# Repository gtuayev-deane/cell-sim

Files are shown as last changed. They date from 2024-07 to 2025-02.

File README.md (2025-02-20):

# Cell Simulator

This cell-sim is designed to mimic a LiPo battery pack for develpoment of the surrounding electronics, like a BMS.

- 16 channels
- Open-Source hardware design, you can embed onto your own HIL setup
- ⚡️ 0-4.5V and 0-500mA per channel
- DMM muxed to each channel for arbitarily precise measurment
- Open-circuit simulation on each channel
- 📏 16bit ADC feedback for voltage and current
- 🔌 USB w/ Python software interface (+ 100MBit Ethernet + WiFi waiting for firmware support)



## Design overview

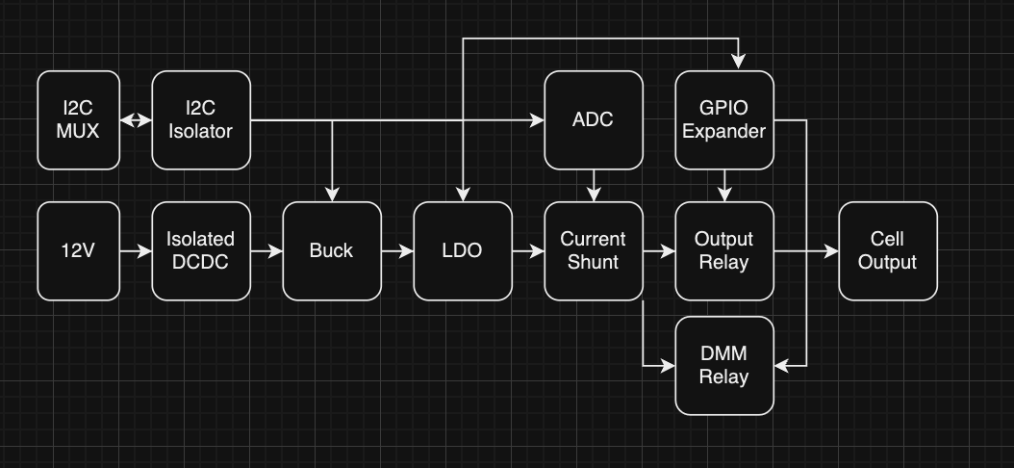
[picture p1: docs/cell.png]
Cell Diagram


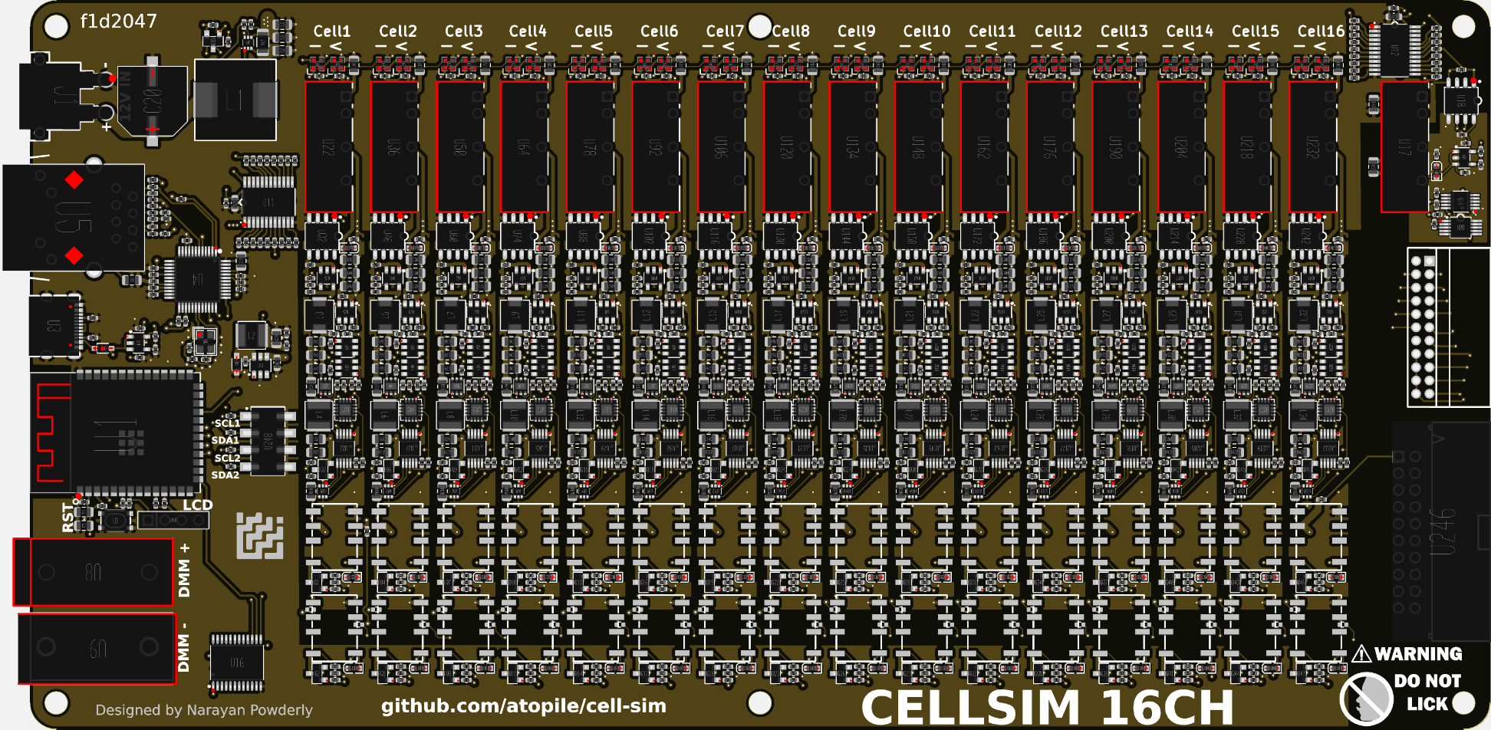
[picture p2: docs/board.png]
Board Render


## Getting Started

1. Install python if you don't have it already
2. Install the requirements `pip install -r requirements.txt`
3. Connect the board via USB
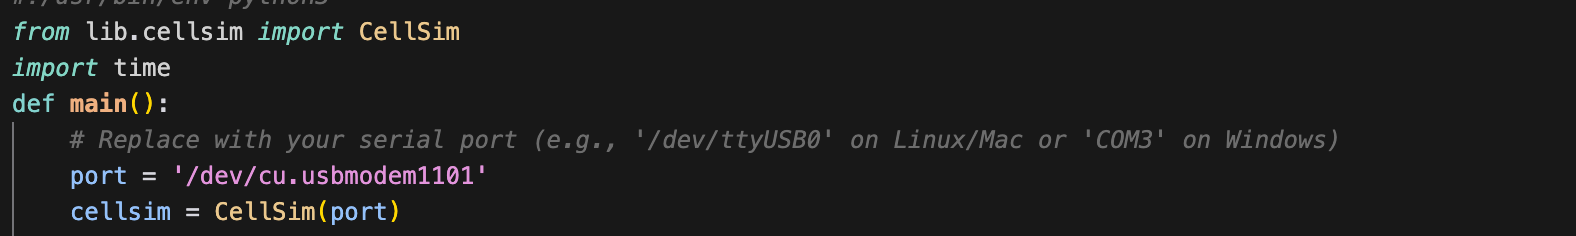
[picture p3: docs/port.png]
Port

4. Power the board with the 12V input (supply: 1A minimum, 3A recommended)
5. Run the example python script `python example_set_voltages.py`
6. Voltages should be set to 3.5V, then rainbow from 1V to 4V across the 16 channels and current should be close to 0A.

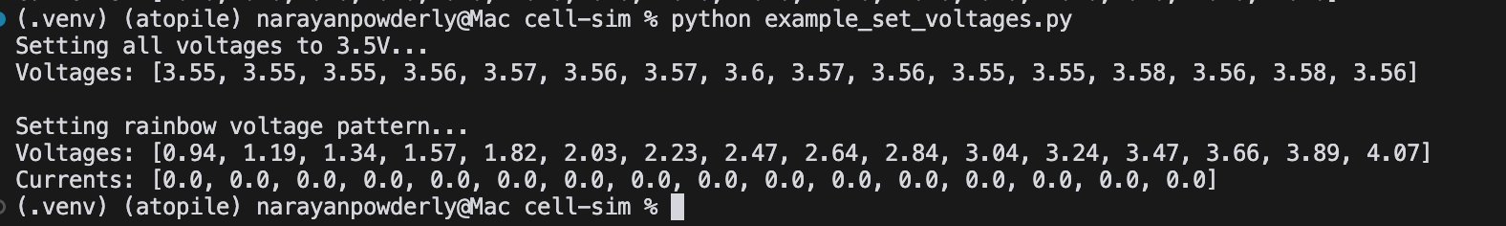
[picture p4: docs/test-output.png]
Test Output


You should see something like this:
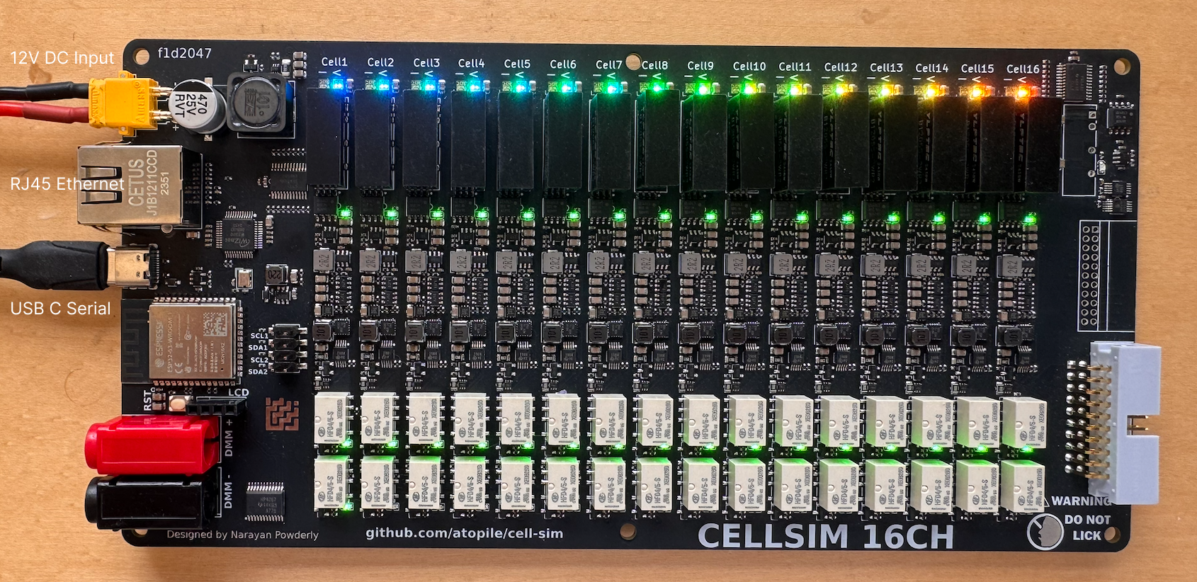
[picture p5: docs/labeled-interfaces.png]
Rainbow


## Notes
1. To get best low noise performance, use a quality power supply for the input supply.

## Firmware

### Update Firmware
We use PlatformIO to build and upload the firmware via USB.
1. Install PlatformIO: https://platformio.org/install
2. Connect the board via USB (might need to accept connection popup on Mac)
3. Run `pio run -t upload` or install the PlatformIO VSCode extension and use the upload button.

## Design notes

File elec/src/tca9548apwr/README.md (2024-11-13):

# TCA9548APWR I2C Multiplexer

The TCA9548APWR is an I2C multiplexer that allows you to connect up to 8 I2C devices with the same address to a single I2C bus. Its kind of weird to need this, but it's a thing.

tca9548apwr



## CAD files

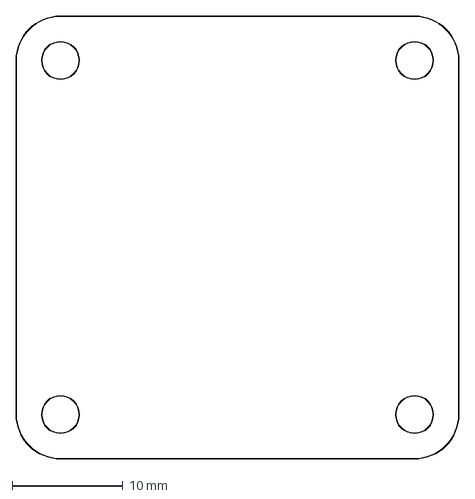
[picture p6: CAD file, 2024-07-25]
elec/src/tca9548apwr/mech/template_40x40.dxf
40.0 x 40.0 mm

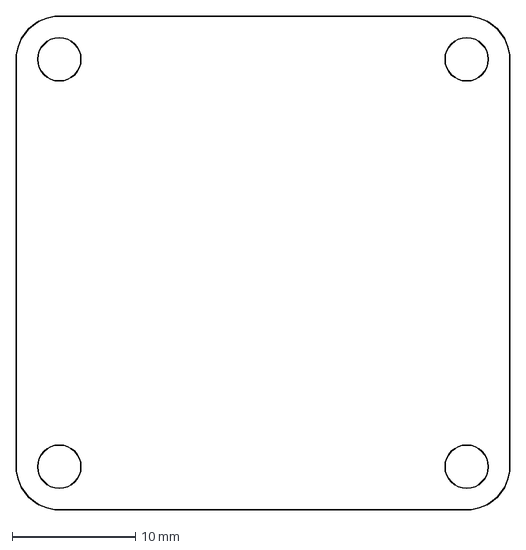
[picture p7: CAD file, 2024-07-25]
elec/src/tca9548apwr/mech/template_outline.dxf
40.0 x 40.0 mm

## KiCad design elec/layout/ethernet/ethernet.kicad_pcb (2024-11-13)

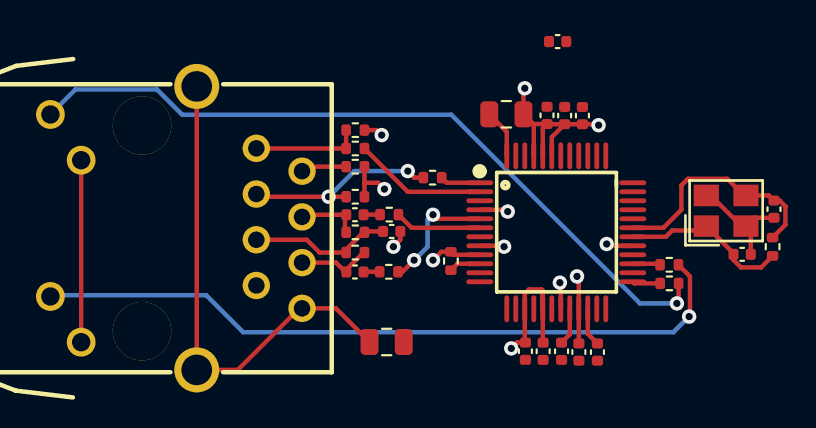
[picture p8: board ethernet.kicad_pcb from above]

Board: 2 copper layers, 32 parts (0 on the bottom side), 27 nets.

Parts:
C1: 50V 1nF X7R ±10% 0805 Multilayer Ceramic Capacito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; C0805
C2: 50V 22nF X7R ±10% 0402 Multilayer Ceramic Capacit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; C0402
C3, C4: 50V 6.8nF X7R ±10% 0402 Multilayer Ceramic Capaci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; C0402
C5, C6: 50V 10nF X7R ±10% 0402 Multilayer Ceramic Capacit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; C0402
C7: 10V 4.7uF X5R ±20% 0402 Multilayer Ceramic Capaci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; C0402
C8, C9, C10, C11, C12, C13: 16V 100nF X7R ±10% 0402 Multilayer Ceramic Capaci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; C0402
C14: 25V 10uF X5R ±10% 0805 Multilayer Ceramic Capacit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; C0805
C15, C16: 50V 10pF C0G ±5% 0402 Multilayer Ceramic Capacito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; C0402
R1, R2: 62.5mW Thick Film Resistors 50V ±100ppm/℃ ±1% 200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; R0402
R3, R4, R8, R9: 62.5mW Thick Film Resistors 50V ±100ppm/℃ ±1% 33Ω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; R0402
R5, R6, R10, R11: 62.5mW Thick Film Resistors 50V ±100ppm/℃ ±1% 49.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; R0402
R7: 62.5mW Thick Film Resistors 50V ±1% ±200ppm/℃ 10Ω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; R0402
R12: 62.5mW Thick Film Resistors 50V ±100ppm/℃ ±1% 12.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; R0402
R13: 62.5mW Thick Film Resistors 50V ±100ppm/℃ ±1% 1MΩ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; R0402
U1: ?; LQFP-48_L7.0-W7.0-P0.50-LS9.0-BL
U2: ?; RJ45-TH_J1B1211CCD
U3: ?; CRYSTAL-SMD_4P-L3.2-W2.5-BL

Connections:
_1v2o: C6.1, U1.22
actled: R2.1, U1.27
cgnd: C1.1, U2.8, U2.13, U2.14
exres1: R12.1, U1.10
gnd-1: C1.2, C2.2, C5.2, C6.2, C7.2, C8.2, C9.2, C10.2, C11.2, C12.2, C13.2, C14.2, R12.2, U1.3, U1.9, U1.14, U1.16, U1.19, U1.29, U1.48
linkled: R1.1, U1.25
lled_minus: R1.2, U2.9
nc: U1.12, U1.13, U1.46, U1.47
oscillator-gnd: C15.2, C16.2, U3.2, U3.4
rct: C5.1, R10.2, R11.2, U2.5
rd_minus: C3.2, R10.1, U2.6
rd_plus: C4.2, R11.1, U2.4
rled_minus: R2.2, U2.11
rsvd: U1.23, U1.38, U1.39, U1.40, U1.41, U1.42
rx_minus_damping-vcc: C3.1, R8.2
rx_plus_damping-vcc: C4.1, R9.2
rxn: R8.1, U1.5
rxp: R9.1, U1.6
tct: C2.1, R7.2, U2.2
td_minus: R4.2, R6.2, U2.3
td_plus: R3.2, R5.2, U2.1
tocap: C7.1, U1.20
txn: R4.1, U1.1
txp: R3.1, U1.2
vcc: C8.1, C9.1, C10.1, C11.1, C12.1, C13.1, C14.1, R5.1, R6.1, R7.1, U1.4, U1.8, U1.11, U1.15, U1.17, U1.21, U1.28, U1.43, U1.44, U1.45, U2.10, U2.12
xi_slash_clkin: C15.1, R13.1, U1.30, U3.1
xo: C16.1, R13.2, U1.31, U3.3

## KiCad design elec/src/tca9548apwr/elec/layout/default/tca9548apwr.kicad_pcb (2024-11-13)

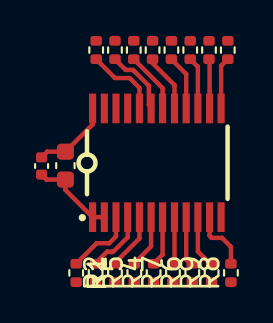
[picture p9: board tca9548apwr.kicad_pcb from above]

Board: 2 copper layers, 20 parts (0 on the bottom side), 19 nets.

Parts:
C1: 16V 100nF X7R ±10% 0402 Multilayer Ceramic Capaci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; C0402
C2: 16V 2.2uF X5R ±10% 0603 Multilayer Ceramic Capaci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; C0603
R1, R2, R3, R4, R5, R6, R7, R8, R9, R10, R11, R12, R13, R14, R15, R16, R17: 62.5mW Thick Film Resistors 50V ±100ppm/℃ ±1% 10k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; R0402
U1: TSSOP-24_L7.8-W4.4-P0.65-LS6.4-BL

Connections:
ic-gnd: C1.2, C2.2, U1.1, U1.2, U1.12, U1.21
ic-scl: R2.2, U1.5
ic-scl-1: R4.2, U1.7
ic-scl-2: R6.2, U1.9
ic-scl-3: R8.2, U1.11
ic-scl-4: R10.2, U1.14
ic-scl-5: R12.2, U1.16
ic-scl-6: R14.2, U1.18
ic-scl-7: R16.2, U1.20
ic-sda: R3.2, U1.4
ic-sda-1: R5.2, U1.6
ic-sda-2: R7.2, U1.8
ic-sda-3: R9.2, U1.10
ic-sda-4: R11.2, U1.13
ic-sda-5: R13.2, U1.15
ic-sda-6: R15.2, U1.17
ic-sda-7: R17.2, U1.19
reset_: R1.1, U1.3
vcc: C1.1, C2.1, R1.2, R2.1, R3.1, R4.1, R5.1, R6.1, R7.1, R8.1, R9.1, R10.1, R11.1, R12.1, R13.1, R14.1, R15.1, R16.1, R17.1, U1.24

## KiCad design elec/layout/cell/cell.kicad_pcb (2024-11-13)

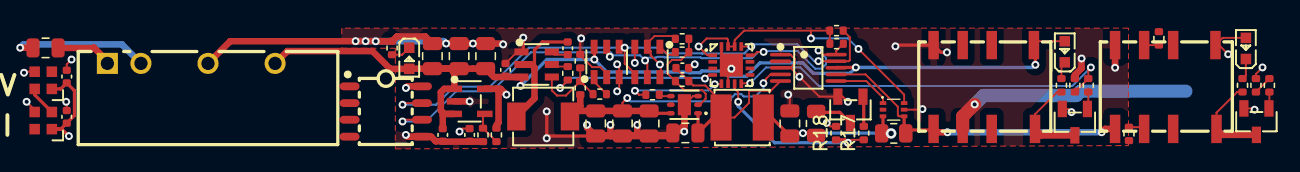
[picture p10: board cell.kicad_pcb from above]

Board: 4 copper layers, 63 parts (0 on the bottom side), 40 nets.

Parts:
C1: 50V 2.2uF X5R ±10% 0805 Multilayer Ceramic Capaci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; C0805
C2, C3, C4, C6, C7, C8, C11, C12: 25V 10uF X5R ±10% 0805 Multilayer Ceramic Capacit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; C0805
C5, C9, C13, C14: 16V 100nF X7R ±10% 0402 Multilayer Ceramic Capaci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; C0402
C10, C15, C16: 25V 1uF X5R ±10% 0402 Multilayer Ceramic Capacito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; C0402
L1: ?; IND-SMD_L4.4-W4.2
L2: ?; IND-SMD_L4.0-W4.0
LED1, LED2, LED3: ?; LED0603-RD
Q1, Q2, Q3: ?; SOT-23-3_L2.9-W1.3-P1.90-LS2.4-BR
R1: 62.5mW Thick Film Resistors 50V ±100ppm/℃ ±1% 14k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; R0402
R2: 62.5mW Thick Film Resistors 50V ±100ppm/℃ ±1% 24k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; R0402
R3: 62.5mW Thick Film Resistors 50V ±100ppm/℃ ±1% 37.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; R0402
R4, R5, R8, R9, R12, R15, R18, R20, R21, R24, R25: 62.5mW Thick Film Resistors 50V ±100ppm/℃ ±1% 10k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; R0402
R6: 62.5mW Thick Film Resistors 50V ±100ppm/℃ ±1% 43k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; R0402
R7: 62.5mW Thick Film Resistors 50V ±100ppm/℃ ±1% 60.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; R0402
R10: 125mW Thick Film Resistors 150V ±1% 100mΩ 0805 Ch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; R0805
R11, R14: 62.5mW Thick Film Resistors 50V ±100ppm/℃ ±1% 13k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; R0402
R13, R16, R17: 62.5mW Thick Film Resistors 50V ±100ppm/℃ ±1% 1kΩ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; R0402
R19: 125mW Thick Film Resistors 150V ±100ppm/℃ ±1% 226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; R0805
R22: 62.5mW Thick Film Resistors 50V ±100ppm/℃ ±1% 11.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; R0402
R23: 62.5mW Thick Film Resistors 50V ±100ppm/℃ ±1% 6.2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; R0402
U1: ?; PWRM-TH_BXXXXS-2WR2
U2: ?; MSOP-10_L3.0-W3.0-P0.50-LS5.0-BL
U3, U4, U5: ?; SOT-23-6_L2.9-W1.6-P0.95-LS2.8-BL
U6: ?; WSON-6_L2.0-W2.0-P0.65-TL-EP
U7: ?; SOT-563_L1.6-W1.2-P0.50-LS1.6-TL
U8, U9: ?; RELAY-SMD_HFD4-5-SR
U10: ?; QFN-16_L3.0-W3.0-P0.50-BL-EP1.7
U11: ?; SOIC-8_L4.9-W3.9-P1.27-LS6.0-TL
U12, U13: ?; LED-SMD_4P-L2.0-W2.0-BR
U14: ?; SOT-23-5_L3.0-W1.7-P0.95-LS2.8-BL

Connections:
adc-vcc: C6.1, C7.1, C8.1, L1.2, R3.1, U2.4, U6.6
adc-vcc-1: C10.1, C11.1, L2.1, R7.1, U2.5, U6.1
adc-vcc-2: R10.2, U2.7, U7.4, U8.5, U9.5
ain2: U2.6, U7.1
buck-enable: R5.1, U10.4
buck.dac-vout: R2.1, U3.1
buck.regulator-en: R5.2, U4.5
dmm_relay-gnd: R25.1, U9.3
dmm_relay-vcc: R24.1, U9.6
dmm_relay.fet-gate: Q2.1, R15.2
dmm_relay.indicator_led.resistor-cathode: LED3.1, R14.1
dmm_relay.relay-gnd: Q2.3, R14.2, U9.8
dmm_relay_enable: R15.1, R16.1
fb: R6.2, R7.2, R8.1, U6.2
gnd: C1.2, U1.2
gnd-2: C13.2, C14.2, Q2.2, R16.2, U12.3, U13.3
gnd-6: C2.2, C3.2, C4.2, C5.2, C6.2, C7.2, C8.2, C10.2, C11.2, C12.2, C15.2, C16.2, Q1.2, Q3.2, R1.2, R4.2, R8.2, R13.2, R18.2, R23.2, U1.4, U2.1, U2.3, U3.2, U4.1, U5.2, U5.6, U6.3, U6.7, U7.2, U7.5, U8.4, U9.4, U10.6, U10.16, U10.17, U11.5, U14.2
input: R12.1, R13.1, U10.8
isolated_converter.led.resistor-cathode: LED1.1, R1.1
ldo-enable: R9.1, U10.5
ldo.dac-vout: R6.1, U5.1
ldo.regulator-en: R9.2, U6.4
load_switch.fet-gate: Q3.1, R17.2
n: Q3.3, R19.2
out: R22.2, R23.1, U14.4
output_relay.fet-gate: Q1.1, R12.2
output_relay.indicator_led.resistor-cathode: LED2.1, R11.1
output_relay.relay-gnd: Q1.3, R11.2, U8.8
p4: R17.1, R18.1, U10.7
scl-1: R21.1, U2.10, U3.5, U5.5, U10.12, U11.6
sda-1: R20.1, U2.9, U3.4, U5.4, U10.13, U11.7
sw: C9.2, L1.1, U4.2
vbst: C9.1, U4.6
vcc: C1.1, U1.1
vcc-2: C13.1, C14.1, LED3.2, U9.1, U12.1, U13.1
vcc-5: C12.1, L2.2, R10.1, R19.1, U7.3
vcc-6: C2.1, C3.1, C4.1, C5.1, C15.1, LED1.2, LED2.2, U1.6, U2.8, U3.6, U4.3, U8.1, U14.1, U14.3
vcc-7: C16.1, R20.2, R21.2, R22.1, U3.3, U5.3, U7.6, U10.1, U10.14, U10.15, U11.8, U14.5
vfb: R2.2, R3.2, R4.1, U4.4
voltage_led.ic-vcc: U12.4, U13.2

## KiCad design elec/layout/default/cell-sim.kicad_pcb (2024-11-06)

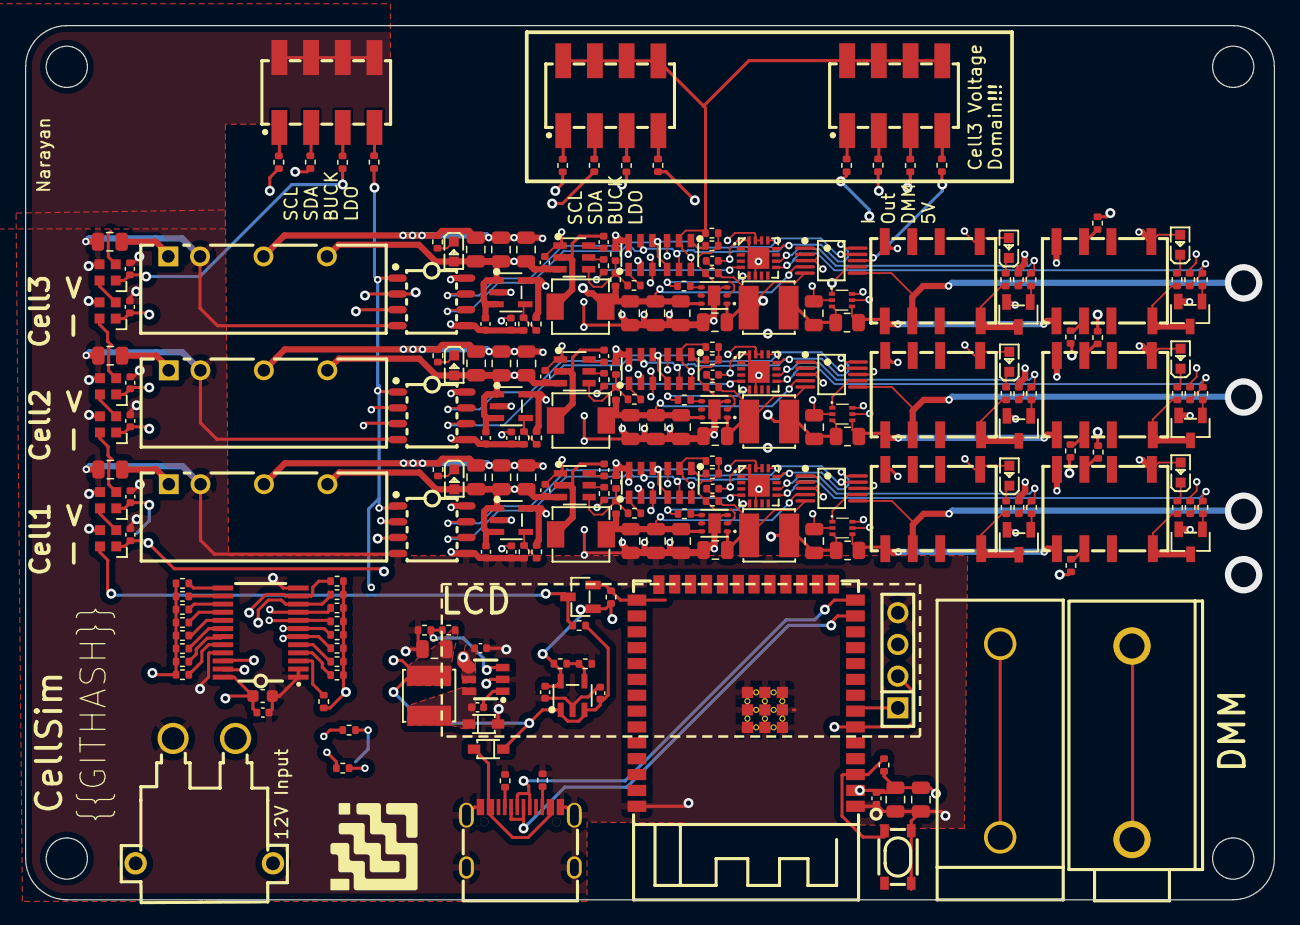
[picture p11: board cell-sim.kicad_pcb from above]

Board: 4 copper layers, 100.0 x 70.0 mm, 238 parts (0 on the bottom side), 150 nets.

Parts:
C1, C4, C8, C15, C19, C23, C24, C31, C35, C39, C40, C47, C51, C55, C56: 16V 100nF X7R ±10% 0402 Multilayer Ceramic Capaci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; C0402
C2, C3, C7, C12, C13, C14, C16, C17, C18, C21, C22, C28, C29, C30, C32, C33, C34, C37, C38, C44, C45, C46, C48, C49, C50, C53, C54: 25V 10uF X5R ±10% 0805 Multilayer Ceramic Capacit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; C0805
C5: 16V 2.2uF X5R ±10% 0603 Multilayer Ceramic Capaci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; C0603
C6: 6.3V 10uF X5R ±20% 0402 Multilayer Ceramic Capaci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; C0402
C9, C10, C20, C25, C26, C36, C41, C42, C52, C57, C58: 25V 1uF X5R ±10% 0402 Multilayer Ceramic Capacito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; C0402
C11, C27, C43: 50V 2.2uF X5R ±10% 0805 Multilayer Ceramic Capaci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; C0805
DS1, DS2: SOD-323_L1.8-W1.3-LS2.5-RD
J1: CONN-TH_XT30PW-M
L1: IND-SMD_L4.0-W4.0
L2, L4, L6: IND-SMD_L4.4-W4.2
L3, L5, L7: 100uH; IND-SMD_L4.0-W4.0
LED1, LED2, LED3, LED4, LED5, LED6, LED7, LED8, LED9: LED0603-RD
Q1, Q2, Q3, Q4, Q5, Q6: SOT-23-3_L2.9-W1.3-P1.90-LS2.4-BR
R1, R4, R5, R6, R7, R8, R9, R10, R11, R12, R13, R14, R15, R16, R17, R18, R19, R20, R27, R28, R32, R33, R36, R37, R40, R43, R47, R48, R52, R53, R56, R57, R60, R63, R67, R68, R72, R73, R76, R77, R80, R83, R87, R88: 62.5mW Thick Film Resistors 50V ±100ppm/℃ ±1% 10k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; R0402
R2, R3: 62.5mW Thick Film Resistors 50V ±100ppm/℃ ±1% 4.7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; R0402
R21, R22: 62.5mW Thick Film Resistors 50V ±100ppm/℃ ±1% 2.2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; R0402
R23: 62.5mW Thick Film Resistors 50V ±1% ±200ppm/℃ 22.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; R0402
R24: 62.5mW Thick Film Resistors 50V ±1% ±100ppm/℃ 4.1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; R0402
R25: 62.5mW Thick Film Resistors 50V ±100ppm/℃ ±1% 17.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; R0402
R26: 62.5mW Thick Film Resistors 50V ±100ppm/℃ ±1% 10.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; R0402
R29, R39, R42, R49, R59, R62, R69, R79, R82: 62.5mW Thick Film Resistors 50V ±100ppm/℃ ±1% 21k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; R0402
R30, R50, R70: 62.5mW Thick Film Resistors 50V ±100ppm/℃ ±1% 24k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; R0402
R31, R51, R71: 62.5mW Thick Film Resistors 50V ±100ppm/℃ ±1% 37.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; R0402
R34, R54, R74: 62.5mW Thick Film Resistors 50V ±100ppm/℃ ±1% 43k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; R0402
R35, R55, R75: 62.5mW Thick Film Resistors 50V ±100ppm/℃ ±1% 59k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; R0402
R38, R58, R78: 125mW Thick Film Resistors ±600ppm/℃ ±1% 110mΩ 08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; R0805
R41, R44, R61, R64, R81, R84, R89, R90, R91, R92, R93, R94, R95, R96, R97, R98, R99, R100: 62.5mW Thick Film Resistors 50V ±100ppm/℃ ±1% 1kΩ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; R0402
R45, R65, R85: 62.5mW Thick Film Resistors 50V ±100ppm/℃ ±1% 11.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; R0402
R46, R66, R86: 62.5mW Thick Film Resistors 50V ±100ppm/℃ ±1% 6.2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; R0402
U1: WIRELM-SMD_ESP32-S3-WROOM-1
U2: KEY-SMD_4P-L4.2-W3.2-P2.20-LS4.6
U3: USB-C-SMD_KH-TYPE-C-16P
U4: AUDIO-TH_24.243.1
U5: CONN-TH_24.243.2
U6: HDR-TH_4P-P2.54-V-F
U7: TSSOP-24_L7.8-W4.4-P0.65-LS6.4-BL
U8: SOT-23-6_L2.9-W1.6-P0.95-LS2.8-BR
U9, U24, U38, U52: SOT-23-5_L3.0-W1.7-P0.95-LS2.8-BL
U10: SOT-23-3_L2.9-W1.3-P1.90-LS2.4-BR
U11, U25, U39: PWRM-TH_BXXXXS-2WR2
U12, U26, U40: MSOP-10_L3.0-W3.0-P0.50-LS5.0-BL
U13, U14, U15, U27, U28, U29, U41, U42, U43: SOT-23-6_L2.9-W1.6-P0.95-LS2.8-BL
U16, U30, U44: WSON-6_L2.0-W2.0-P0.65-TL-EP
U17, U31, U45: SOT-563_L1.6-W1.2-P0.50-LS1.6-TL
U18, U19, U32, U33, U46, U47: RELAY-SMD_HFD4-5-SR
U20, U34, U48: QFN-16_L3.0-W3.0-P0.50-BL-EP1.7
U21, U35, U49: SOIC-8_L4.9-W3.9-P1.27-LS6.0-TL
U22, U23, U36, U37, U50, U51: LED-SMD_4P-L2.0-W2.0-BR
U53, U54, U55: HDR-SMD_8P-P2.54-V-M-R2-C4-LS7.4

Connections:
buck.feedback_div-out: R23.2, R24.1, U8.3
buck.ic-sw: C8.2, DS1.1, L1.1, U8.6
cb: C8.1, U8.1
cc1: R2.1, U3.A5
cc2: R3.1, U3.B5
cell1-gnd: C22.1, C28.2, C29.2, C30.2, C31.2, C32.2, C33.2, C34.2, C36.2, C37.2, C38.2, C41.2, C42.2, L3.2, Q3.2, Q4.2, R38.1, R49.2, R52.2, R56.2, R61.2, R64.2, R66.2, U17.3, U25.4, U26.1, U26.3, U27.2, U28.1, U29.2, U29.6, U30.3, U30.7, U31.2, U31.5, U32.4, U33.4, U34.6, U34.16, U34.17, U35.5, U38.2
cell1-led_data: U22.2, U37.4
cell1-scl: U12.10, U13.5, U15.5, U20.12, U21.6
cell1-sda: U12.9, U13.4, U15.4, U20.13, U21.7
cell1-vcc: U12.6, U18.6
cell1-vcc-1: C12.1, C13.1, C14.1, C15.1, C25.1, LED1.2, LED2.2, LED3.2, U11.6, U13.6, U14.3, U18.1, U19.1, U24.1, U24.3
cell1-vcc-2: C26.1, R45.1, U12.8, U13.3, U15.3, U17.6, U20.14, U20.15, U21.8, U24.5
cell1.adc-ain3: U12.7, U17.1
cell1.adc-vcc: C16.1, C17.1, C18.1, L2.2, R31.1, U12.4, U16.6
cell1.adc-vcc-1: C20.1, C21.1, L3.1, R35.1, U12.5, U16.1
cell1.buck-enable: R33.1, U20.4
cell1.buck.ctrl_resistor-vfb: R30.2, R31.2, R32.1, U14.4
cell1.buck.dac-vout: R30.1, U13.1
cell1.buck.regulator-en: R33.2, U14.5
cell1.buck.regulator-sw: C19.2, L2.1, U14.2
cell1.buck.regulator-vbst: C19.1, U14.6
cell1.current_sense.sensor-vcc: R38.2, U17.4, U18.5, U19.5
cell1.dmm_relay-gnd: R48.1, U19.3
cell1.dmm_relay-input: R43.1, R44.1, U20.9
cell1.dmm_relay-vcc: R47.1, U19.6
cell1.dmm_relay.fet-gate: Q2.1, R43.2
cell1.dmm_relay.indicator_led.resistor-cathode: LED3.1, R42.1
cell1.dmm_relay.relay-gnd: Q2.3, R42.2, U19.8
cell1.internal_ldo.feedback_div-out: R45.2, R46.1, U24.4
cell1.isolated_converter.led.resistor-cathode: LED1.1, R29.1
cell1.ldo-enable: R37.1, U20.5
cell1.ldo.ctrl_resistor-fb: R34.2, R35.2, R36.1, U16.2
cell1.ldo.dac-vout: R34.1, U15.1
cell1.ldo.regulator-en: R37.2, U16.4
cell1.output_relay-input: R40.1, R41.1, U20.10
cell1.output_relay.fet-gate: Q1.1, R40.2
cell1.output_relay.indicator_led.resistor-cathode: LED2.1, R39.1
cell1.output_relay.relay-gnd: Q1.3, R39.2, U18.8
cell1.voltage_led.ic-vcc: U22.4, U23.2
cell2-gnd-1: C38.1, C44.2, C45.2, C46.2, C47.2, C48.2, C49.2, C50.2, C52.2, C53.2, C54.2, C57.2, C58.2, L5.2, Q5.2, Q6.2, R58.1, R69.2, R72.2, R76.2, R81.2, R84.2, R86.2, U31.3, U39.4, U40.1, U40.3, U41.2, U42.1, U43.2, U43.6, U44.3, U44.7, U45.2, U45.5, U46.4, U47.4, U48.6, U48.16, U48.17, U49.5, U52.2, U54.2, U54.4, U54.6, U54.8, U55.2, U55.4, U55.6, U55.8
cell2-led_data: U36.2, U51.4
cell2-scl: U26.10, U27.5, U29.5, U34.12, U35.6
cell2-sda: U26.9, U27.4, U29.4, U34.13, U35.7
cell2-vcc: U26.6, U32.6
cell2-vcc-1: C28.1, C29.1, C30.1, C31.1, C41.1, LED4.2, LED5.2, LED6.2, U25.6, U27.6, U28.3, U32.1, U33.1, U38.1, U38.3
cell2-vcc-2: C42.1, R65.1, U26.8, U27.3, U29.3, U31.6, U34.14, U34.15, U35.8, U38.5
cell2.adc-ain3: U26.7, U31.1
cell2.adc-vcc: C32.1, C33.1, C34.1, L4.2, R51.1, U26.4, U30.6
cell2.adc-vcc-1: C36.1, C37.1, L5.1, R55.1, U26.5, U30.1
cell2.buck-enable: R53.1, U34.4
cell2.buck.ctrl_resistor-vfb: R50.2, R51.2, R52.1, U28.4
cell2.buck.dac-vout: R50.1, U27.1
cell2.buck.regulator-en: R53.2, U28.5
cell2.buck.regulator-sw: C35.2, L4.1, U28.2
cell2.buck.regulator-vbst: C35.1, U28.6
cell2.current_sense.sensor-vcc: R58.2, U31.4, U32.5, U33.5
cell2.dmm_relay-gnd: R68.1, U33.3
cell2.dmm_relay-input: R63.1, R64.1, U34.9
cell2.dmm_relay-vcc: R67.1, U33.6
cell2.dmm_relay.fet-gate: Q4.1, R63.2
cell2.dmm_relay.indicator_led.resistor-cathode: LED6.1, R62.1
cell2.dmm_relay.relay-gnd: Q4.3, R62.2, U33.8
cell2.internal_ldo.feedback_div-out: R65.2, R66.1, U38.4
cell2.isolated_converter.led.resistor-cathode: LED4.1, R49.1
cell2.ldo-enable: R57.1, U34.5
cell2.ldo.ctrl_resistor-fb: R54.2, R55.2, R56.1, U30.2
cell2.ldo.dac-vout: R54.1, U29.1
cell2.ldo.regulator-en: R57.2, U30.4
cell2.output_relay-input: R60.1, R61.1, U34.10
cell2.output_relay.fet-gate: Q3.1, R60.2
cell2.output_relay.indicator_led.resistor-cathode: LED5.1, R59.1
cell2.output_relay.relay-gnd: Q3.3, R59.2, U32.8
cell2.voltage_led.ic-vcc: U36.4, U37.2
cell3-scl: R93.1, U40.10, U41.5, U43.5, U48.12, U49.6
cell3-sda: R94.1, U40.9, U41.4, U43.4, U48.13, U49.7
cell3-vcc: C54.1, L7.2, R78.1, U45.3
cell3-vcc-1: C44.1, C45.1, C46.1, C47.1, C57.1, LED7.2, LED8.2, LED9.2, U39.6, U41.6, U42.3, U46.1, U47.1, U52.1, U52.3
cell3-vcc-2: C58.1, R85.1, R100.1, U40.8, U41.3, U43.3, U45.6, U48.14, U48.15, U49.8, U52.5
cell3.adc-ain3: R97.1, U40.7, U45.1
cell3.adc-vcc: C48.1, C49.1, C50.1, L6.2, R71.1, R95.1, U40.4, U44.6
cell3.adc-vcc-1: C52.1, C53.1, L7.1, R75.1, R96.1, U40.5, U44.1
cell3.buck-enable: R73.1, U48.4
cell3.buck.ctrl_resistor-vfb: R70.2, R71.2, R72.1, U42.4
cell3.buck.dac-vout: R70.1, U41.1
cell3.buck.regulator-en: R73.2, U42.5
cell3.buck.regulator-sw: C51.2, L6.1, U42.2
cell3.buck.regulator-vbst: C51.1, U42.6
cell3.current_sense.sensor-vcc: R78.2, U45.4, U46.5, U47.5
cell3.dmm_relay-gnd: R88.1, U47.3
cell3.dmm_relay-input: R83.1, R84.1, R99.1, U48.9
cell3.dmm_relay-vcc: R87.1, U47.6
cell3.dmm_relay.fet-gate: Q6.1, R83.2
cell3.dmm_relay.indicator_led.resistor-cathode: LED9.1, R82.1
cell3.dmm_relay.relay-gnd: Q6.3, R82.2, U47.8
cell3.internal_ldo.feedback_div-out: R85.2, R86.1, U52.4
cell3.isolated_converter.led.resistor-cathode: LED7.1, R69.1
cell3.ldo-enable: R77.1, U48.5
cell3.ldo.ctrl_resistor-fb: R74.2, R75.2, R76.1, U44.2
cell3.ldo.dac-vout: R74.1, U43.1
cell3.ldo.regulator-en: R77.2, U44.4
cell3.output_relay-input: R80.1, R81.1, R98.1, U48.10
cell3.output_relay.fet-gate: Q5.1, R80.2
cell3.output_relay.indicator_led.resistor-cathode: LED8.1, R79.1
cell3.output_relay.relay-gnd: Q5.3, R79.2, U46.8
cell3.voltage_led.ic-vcc: U50.4, U51.2
cell3_debug_1.header-_1: R93.2, U54.1
cell3_debug_1.header-_3: R94.2, U54.3
cell3_debug_1.header-_5: R95.2, U54.5
cell3_debug_1.header-_7: R96.2, U54.7
cell3_debug_2.header-_1: R97.2, U55.1
cell3_debug_2.header-_3: R98.2, U55.3
cell3_debug_2.header-_5: R99.2, U55.5
cell3_debug_2.header-_7: R100.2, U55.7
dm: U1.13, U3.A7, U3.B7
dp: U1.14, U3.A6, U3.B6
gnd: C1.2, C2.2, C3.2, C4.2, C5.2, C6.2, C7.2, C9.2, C10.2, C11.2, C12.2, C13.2, C14.2, C15.2, C16.2, C17.2, C18.2, C20.2, C21.2, C22.2, C23.2, C24.2, C25.2, C26.2, C27.2, C39.2, C40.2, C43.2, C55.2, C56.2, DS1.2, J1.1, Q1.2, Q2.2, R2.2, R3.2, R24.2, R26.2, R29.2, R32.2, R36.2, R41.2, R44.2, R46.2, U1.1, U1.40, U1.41, U2.3, U2.4, U3.1, U3.2, U3.3, U3.4, U3.A1, U3.A12, U3.B1, U3.B12, U6.4, U7.1, U7.2, U7.12, U7.21, U8.2, U9.2, U11.2, U11.4, U12.1, U12.3, U13.2, U14.1, U15.2, U15.6, U16.3, U16.7, U17.2, U17.5, U18.4, U19.4, U20.6, U20.16, U20.17, U21.4, U21.5, U22.3, U23.3, U24.2, U25.2, U35.4, U36.3, U37.3, U39.2, U49.4, U50.3, U51.3, U53.2, U53.4, U53.6, U53.8
gnd-2: R48.2, R68.2, R88.2, U5.1, U5.2
hv_signal: R28.2, U10.3, U23.4
i2c_debug.header-_1: R89.2, U53.1
i2c_debug.header-_3: R90.2, U53.3
i2c_debug.header-_5: R91.2, U53.5
i2c_debug.header-_7: R92.2, U53.7
io0: R27.2, U1.27, U10.2
ldo3v3.feedback_div-out: R25.2, R26.1, U9.4
micro.ic-en: R1.2, U1.3, U2.1, U2.2
micro.ic-scl: R22.1, R89.1, U1.6, U6.2, U7.22
micro.ic-sda: R21.1, R90.1, U1.7, U6.1, U7.23
mux.ic-scl: R5.2, U7.5
mux.ic-scl-1: R7.2, U7.7, U21.3
mux.ic-scl-2: R9.2, U7.9, U35.3
mux.ic-scl-3: R11.2, U7.11, U49.3
mux.ic-scl-4: R13.2, U7.14
mux.ic-scl-5: R15.2, U7.16
mux.ic-scl-6: R17.2, U7.18
mux.ic-scl-7: R19.2, U7.20
mux.ic-sda: R6.2, U7.4
mux.ic-sda-1: R8.2, U7.6, U21.2
mux.ic-sda-2: R10.2, U7.8, U35.2
mux.ic-sda-3: R12.2, U7.10, U49.2
mux.ic-sda-4: R14.2, U7.13
mux.ic-sda-5: R16.2, U7.15
mux.ic-sda-6: R18.2, U7.17
mux.ic-sda-7: R20.2, U7.19
reset_: R4.1, U7.3
usbc-vcc: DS2.2, U3.A4, U3.A9, U3.B4, U3.B9
vcc: C6.1, C11.1, C27.1, C43.1, J1.2, U8.4, U8.5, U11.1, U25.1, U39.1
vcc-1: U40.6, U46.6
vcc-2: C7.1, C9.1, C23.1, C24.1, C39.1, C40.1, C55.1, C56.1, DS2.1, L1.2, R23.1, R28.1, R91.1, U9.1, U9.3, U22.1, U23.1, U36.1, U37.1, U50.1, U51.1
vcc-3: C1.1, C2.1, C3.1, C4.1, C5.1, C10.1, R1.1, R4.2, R5.1, R6.1, R7.1, R8.1, R9.1, R10.1, R11.1, R12.1, R13.1, R14.1, R15.1, R16.1, R17.1, R18.1, R19.1, R20.1, R21.2, R22.2, R25.1, R27.1, R92.1, U1.2, U6.3, U7.24, U9.5, U10.1, U21.1, U35.1, U49.1
vcc-4: R47.2, R67.2, R87.2, U4.1, U4.2

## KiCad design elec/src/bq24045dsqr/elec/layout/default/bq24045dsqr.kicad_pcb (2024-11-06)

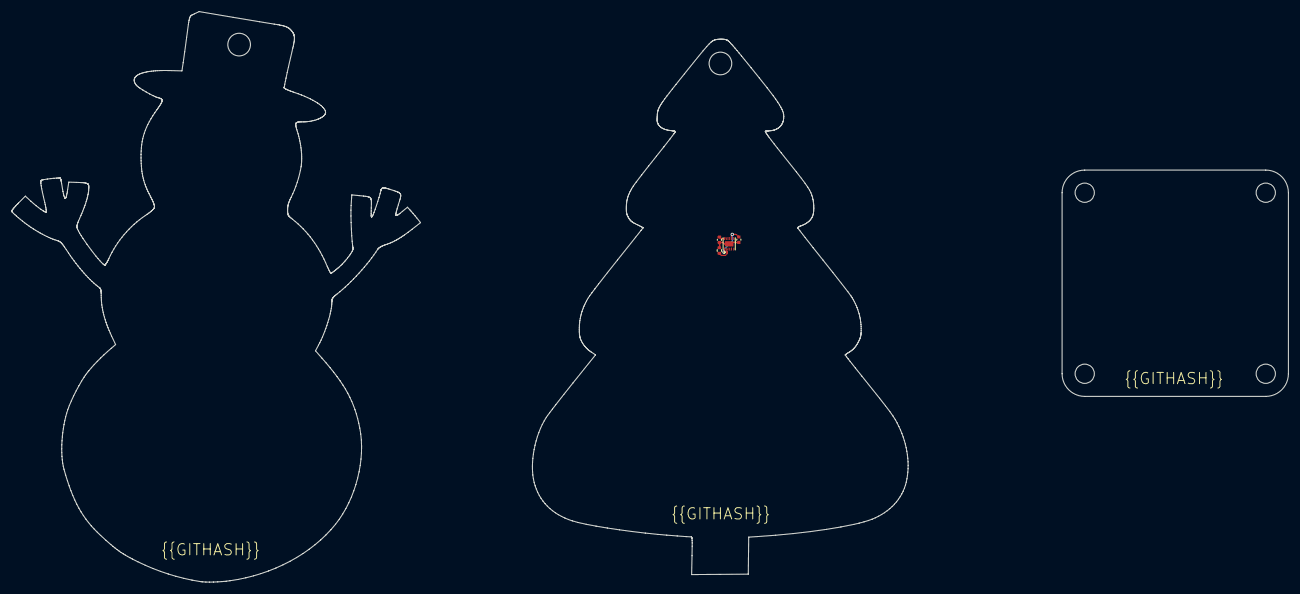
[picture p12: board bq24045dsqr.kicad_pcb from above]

Board: 2 copper layers, 66.4 x 94.6 mm, 4 parts (0 on the bottom side), 4 nets.

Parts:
C1, C2: 25V 1uF X5R ±10% 0402 Multilayer Ceramic Capacito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; C0402
R1: 100mW Thick Film Resistors ±100ppm/℃ ±1% 604Ω 040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; R0402
U1: WSON-10_L2.0-W2.0-P0.40-BL-EP

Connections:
ic-gnd: C1.2, C2.2, R1.2, U1.3, U1.11
ic-vcc: C1.1, U1.1, U1.7
ic-vcc-1: C2.1, U1.10
iset: R1.1, U1.2

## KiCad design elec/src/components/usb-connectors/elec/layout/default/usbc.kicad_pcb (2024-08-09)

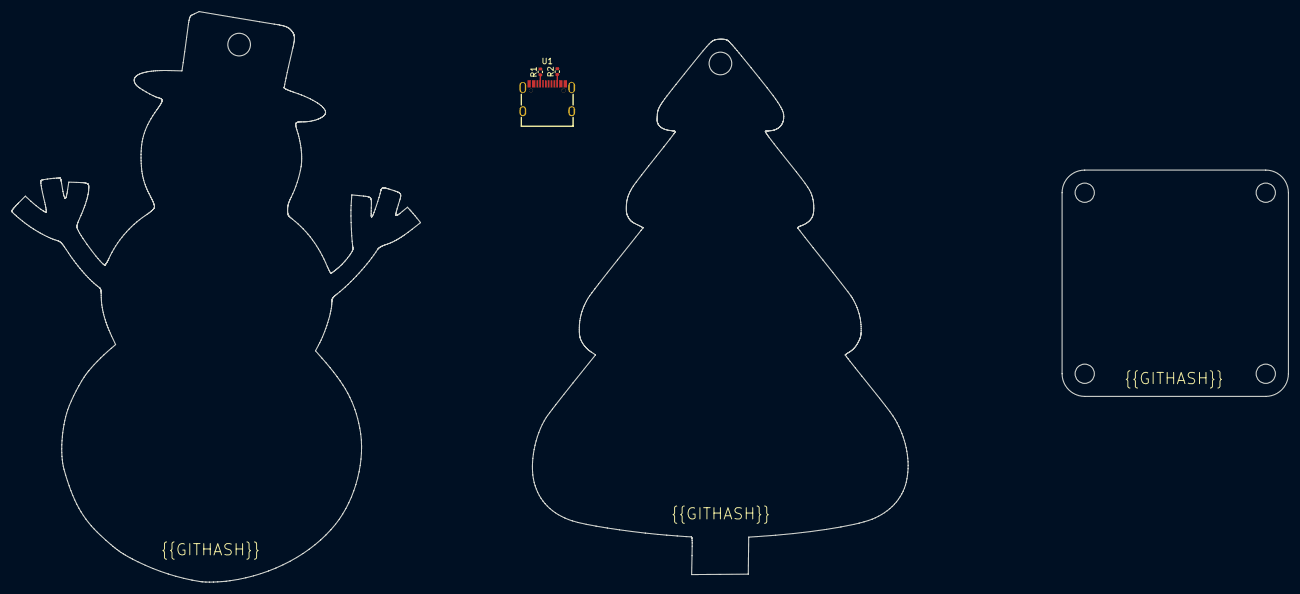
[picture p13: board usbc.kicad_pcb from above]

Board: 2 copper layers, 66.4 x 94.6 mm, 3 parts (0 on the bottom side), 6 nets.

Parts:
R1, R2: Chip Resistor - Surface Mount 4.7KOhms ±5% 1/16W 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; R0402
U1: USB-C-SMD_KH-TYPE-C-16P

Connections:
cc1: R1.1, U1.A5
cc2: R2.1, U1.B5
dm: U1.A7, U1.B7
dp: U1.A6, U1.B6
gnd: R1.2, R2.2, U1.1, U1.2, U1.3, U1.4, U1.A1, U1.A12, U1.B1, U1.B12
vcc: U1.A4, U1.A9, U1.B4, U1.B9

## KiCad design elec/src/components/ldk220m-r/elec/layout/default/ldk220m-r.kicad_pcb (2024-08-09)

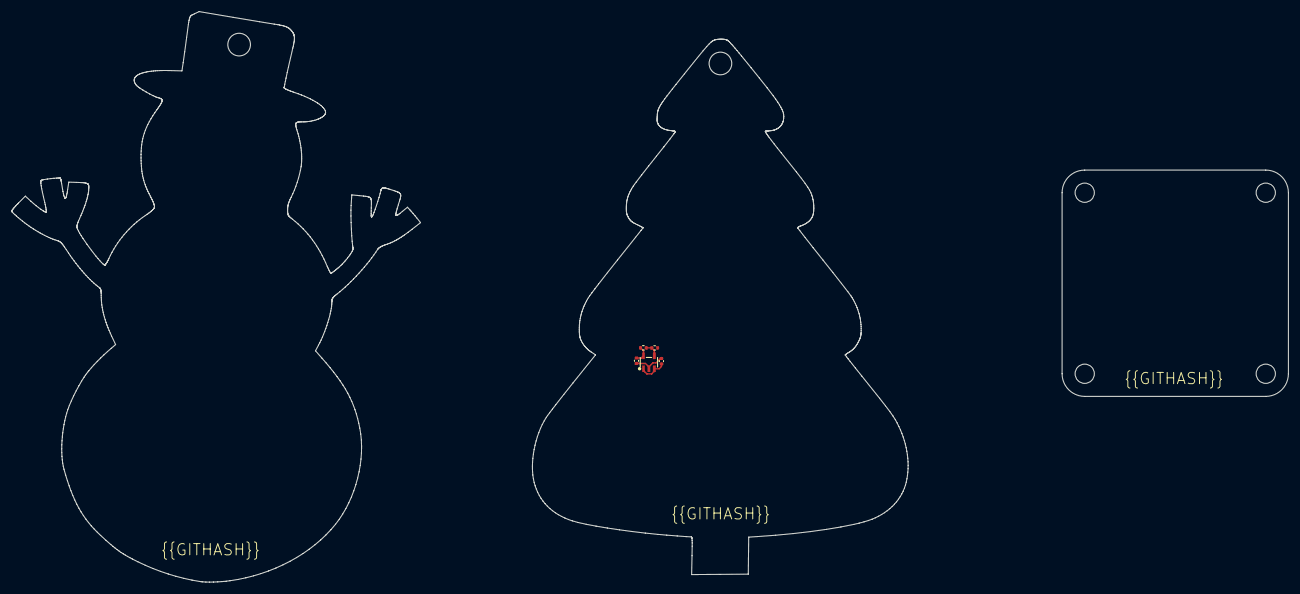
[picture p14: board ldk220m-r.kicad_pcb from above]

Board: 2 copper layers, 66.4 x 94.6 mm, 5 parts (0 on the bottom side), 4 nets.

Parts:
C1, C2: Multilayer Ceramic Capacitors MLCC - SMD/SMT 1uF 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; C0402
R1: Chip Resistor - Surface Mount 18KOhms ±5% 1/16W 0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; R0402
R2: Chip Resistor - Surface Mount 10KOhms ±5% 1/16W 0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; R0402
U1: SOT-23-5_L3.0-W1.7-P0.95-LS2.8-BL

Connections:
gnd: C1.2, C2.2, R2.2, U1.2
out: R1.2, R2.1, U1.4
vcc: C1.1, U1.1, U1.3
vcc-1: C2.1, R1.1, U1.5

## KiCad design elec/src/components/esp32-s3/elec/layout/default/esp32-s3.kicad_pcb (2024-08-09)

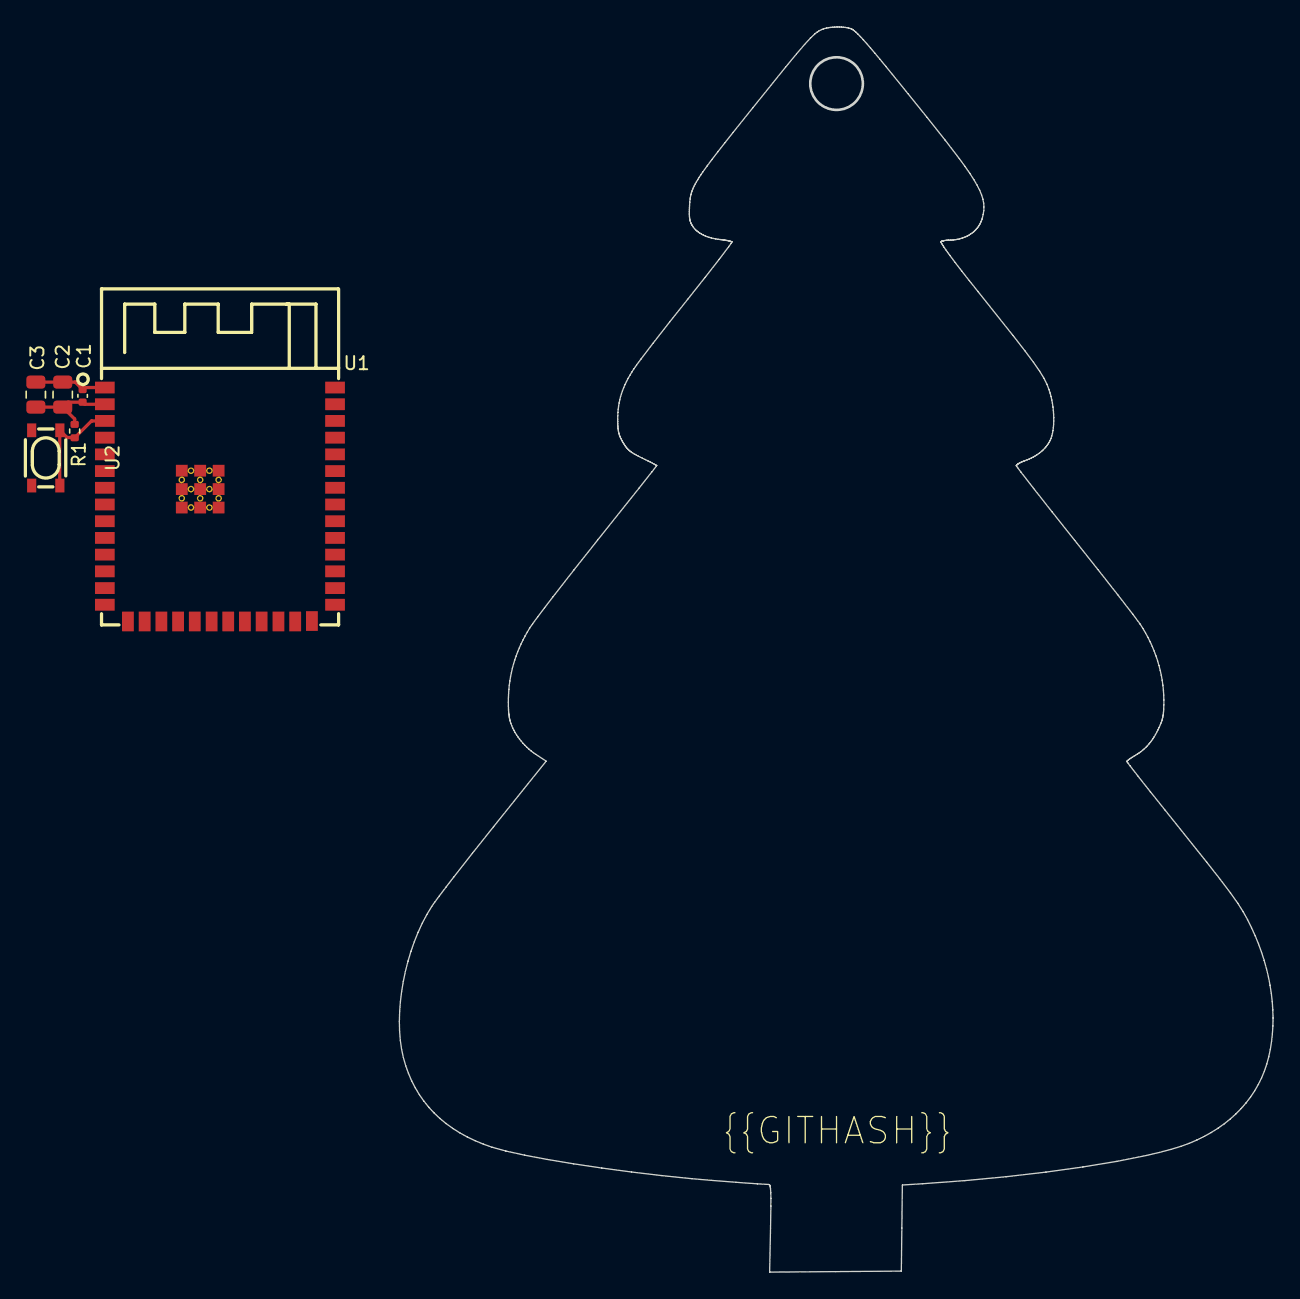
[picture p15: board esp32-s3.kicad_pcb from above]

Board: 2 copper layers, 66.4 x 94.6 mm, 6 parts (0 on the bottom side), 3 nets.

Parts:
C1: 16V 100nF X7R ±10% 0402 Multilayer Ceramic Capaci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; C0402
C2, C3: 25V 10uF X5R ±10% 0805 Multilayer Ceramic Capacit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; C0805
R1: 62.5mW Thick Film Resistors ±100ppm/℃ ±1% 10kΩ 04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; R0402
U1: WIRELM-SMD_ESP32-S3-WROOM-1
U2: KEY-SMD_4P-L4.2-W3.2-P2.20-LS4.6

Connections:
en: R1.2, U1.3, U2.1, U2.2
ic-gnd: C1.2, C2.2, C3.2, U1.1, U1.40, U1.41, U2.3, U2.4
vcc: C1.1, C2.1, C3.1, R1.1, U1.2

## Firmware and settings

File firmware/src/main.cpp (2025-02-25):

#include <Arduino.h>
#include <Wire.h>
#include <SPI.h>
#include <Cell.h>
// #include <Adafruit_SSD1306.h> // OLEDå
#include <Adafruit_MCP4725.h> // DAC
#include <Adafruit_ADS1X15.h> // ADC
#include <FastLED.h>          // Addressable LEDs

// Pin definitions

// LED
const int ledPin = 15;

// I2C
const int wire_1_sdaPin = 7;
const int wire_1_sclPin = 6;
const int wire_2_sdaPin = 17;
const int wire_2_sclPin = 18;

// SPI2
const int spi_2_sckPin = 12;
const int spi_2_mosiPin = 11;
const int spi_2_misoPin = 13;
const int spi_2_csPin = 10;

// DMM MUX
const int DMM_MUX_PINS[] = {1, 2, 3, 4};
const int DMM_MUX_ENABLE = 5;

// Addressable LEDs
#define NUM_LEDS 32
CRGB leds[NUM_LEDS];

// Create cells
Cell cell1(0, Wire);
Cell cell2(1, Wire);
Cell cell3(2, Wire);
Cell cell4(3, Wire);
Cell cell5(4, Wire);
Cell cell6(5, Wire);
Cell cell7(6, Wire);
Cell cell8(7, Wire);
Cell cell9(0, Wire1);
Cell cell10(1, Wire1);
Cell cell11(2, Wire1);
Cell cell12(3, Wire1);
Cell cell13(4, Wire1);
Cell cell14(5, Wire1);
Cell cell15(6, Wire1);
Cell cell16(7, Wire1);

// Cell array
Cell cells[] = {cell1, cell2, cell3, cell4, cell5, cell6, cell7, cell8, cell9, cell10, cell11, cell12, cell13, cell14, cell15, cell16};

float voltageTargets[16];

void setupLEDs()
{
    FastLED.addLeds<NEOPIXEL, ledPin>(leds, NUM_LEDS);
}

void updateStatusLEDs(Cell* cells, size_t num_cells) {
    // Constants for voltage range
    const float MIN_VOLTAGE = 0.5;  // Minimum voltage
    const float MAX_VOLTAGE = 4.5;  // Maximum voltage
    const float MAX_CURRENT = 0.5;  // Maximum current in amps
    
    // Update LEDs for each cell (2 LEDs per cell)
    for (size_t i = 0; i < num_cells && i*2 < NUM_LEDS; i++) {
        float voltage = cells[i].getVoltage();
        float current = cells[i].getCurrent();
        
        // Calculate voltage position in range 0-1
        float voltage_pos = constrain((voltage - MIN_VOLTAGE) / (MAX_VOLTAGE - MIN_VOLTAGE), 0, 1);
        uint8_t current_bright = constrain((current / MAX_CURRENT) * 255, 0, 255);

        // Create color gradient for voltage (blue->green->red)
        CRGB voltage_color;
        if (voltage_pos < 0.5) {
            // Blue to green (0-0.5)
            float pos = voltage_pos * 2;
            voltage_color = CRGB(0, 255 * pos, 255 * (1 - pos));
        } else {
            // Green to red (0.5-1.0)
            float pos = (voltage_pos - 0.5) * 2;
            voltage_color = CRGB(255 * pos, 255 * (1 - pos), 0);
        }

        // Set LED colors - Current LED is red, Voltage LED is color gradient
        leds[i*2] = CRGB(current_bright, 0, 0);     // Current LED
        leds[i*2 + 1] = voltage_color;              // Voltage LED
    }

    FastLED.show();
}

void setup()
{
    USBSerial.begin(115200);
    Wire.setPins(wire_1_sdaPin, wire_1_sclPin);
    Wire.begin();
    Wire1.setPins(wire_2_sdaPin, wire_2_sclPin);
    Wire1.begin();

    // SPI2
    // SPI.begin(12, 13, 11, 10); // SCK, MISO, MOSI, CS
    // SPI.setClockDivider(SPI_CLOCK_DIV8);
    // SPI.setBitOrder(MSBFIRST);
    // SPI.setDataMode(SPI_MODE0);

    // Setup mux
    pinMode(DMM_MUX_ENABLE, OUTPUT);
    for (int i = 0; i < 4; i++) {
        pinMode(DMM_MUX_PINS[i], OUTPUT);
        digitalWrite(DMM_MUX_PINS[i], LOW);
    }

    // Initialize voltage targets for each of the 16 cells
    for (int i = 0; i < 16; i++) {
        voltageTargets[i] = 3.5;
    }

    delay(1000);

    // Initialize cells
    for (Cell& cell : cells) {
        cell.init();
        cell.enable();
        cell.turnOnOutputRelay();
        cell.calibrate();
    }

    FastLED.addLeds<NEOPIXEL, ledPin>(leds, NUM_LEDS);
    FastLED.setBrightness(255);
}

void processUARTCommands() {
    if (USBSerial.available()) {
        String cmd = USBSerial.readStringUntil('\n');
        cmd.trim();
        if (cmd.length() == 0) return;

        int firstSpace = cmd.indexOf(' ');
        String command = cmd;
        String args = "";
        if (firstSpace != -1) {
            command = cmd.substring(0, firstSpace);
            args = cmd.substring(firstSpace + 1);
        }
        command.toUpperCase();

        if (command == "SETV") {
            int spaceIndex = args.indexOf(' ');
            if (spaceIndex == -1) {
                USBSerial.println("Error:SETV requires two arguments");
                return;
            }
            String cellStr = args.substring(0, spaceIndex);
            String voltageStr = args.substring(spaceIndex + 1);
            int cellNumber = cellStr.toInt();
            float voltageValue = voltageStr.toFloat();
            if (cellNumber < 1 || cellNumber > 16) {
                USBSerial.println("Error:cell number must be between 1 and 16");
                return;
            }
            voltageTargets[cellNumber - 1] = voltageValue;
            USBSerial.print("OK:voltage_set:");
            USBSerial.println(voltageValue);
        } else if (command == "GETV") {
            int cellNumber = args.toInt();
            if (cellNumber < 1 || cellNumber > 16) {
                USBSerial.println("Error:cell number must be between 1 and 16");
                return;
            }
            float volt = cells[cellNumber - 1].getVoltage();
            USBSerial.print("OK:voltage:");
            USBSerial.println(volt, 5);
        } else if (command == "ENABLE_OUTPUT") {
            int cellNumber = args.toInt();
            if (cellNumber < 1 || cellNumber > 16) {
                USBSerial.println("Error:cell number must be between 1 and 16");
                return;
            }
            cells[cellNumber - 1].turnOnOutputRelay();
            USBSerial.print("OK:output_enabled:");
            USBSerial.println(cellNumber);
        } else if (command == "ENABLE_DMM") {
            int cellNumber = args.toInt();
            if (cellNumber < 1 || cellNumber > 16) {
                USBSerial.println("Error:cell number must be between 1 and 16");
                return;
            }
            int channel = cellNumber - 1;
            for (int i = 0; i < 4; i++) {
                int bitVal = (channel >> i) & 0x01;
                digitalWrite(DMM_MUX_PINS[i], bitVal ? HIGH : LOW);
            }
            digitalWrite(DMM_MUX_ENABLE, LOW);
            USBSerial.print("OK:dmm_enabled:");
            USBSerial.println(cellNumber);
        } else if (command == "DISABLE_DMM") {
            digitalWrite(DMM_MUX_ENABLE, HIGH);
            USBSerial.println("OK:dmm_disabled");
        } else if (command == "GETALLV") {
            String response = "OK:voltages:";
            for (int i = 0; i < 16; i++) {
                if (i > 0) response += ",";
                response += String(cells[i].getVoltage(), 2);
            }
            USBSerial.println(response);
        } else if (command == "GETALLI") {
            String response = "OK:currents:";
            for (int i = 0; i < 16; i++) {
                if (i > 0) response += ",";
                response += String(cells[i].getCurrent(), 2);
            }
            USBSerial.println(response);
        } else if (command == "SETALLV") {
            if (args.length() == 0) {
                USBSerial.println("Error:SETALLV requires one argument");
                return;
            }
            float voltage = args.toFloat();
            for (int i = 0; i < 16; i++) {
                voltageTargets[i] = voltage;
            }
            USBSerial.print("OK:all_voltages_set:");
            USBSerial.println(voltage);
        } else if (command == "ENABLE_OUTPUT_ALL") {
            for (int i = 0; i < 16; i++) {
                cells[i].turnOnOutputRelay();
            }
            USBSerial.println("OK:all_outputs_enabled");
        } else if (command == "DISABLE_OUTPUT_ALL") {
            for (int i = 0; i < 16; i++) {
                cells[i].turnOffOutputRelay();
            }
            USBSerial.println("OK:all_outputs_disabled");
        } else if (command == "ENABLE_OUTPUT") {
            int cellNumber = args.toInt();
            if (cellNumber < 1 || cellNumber > 16) {
                USBSerial.println("Error:cell number must be between 1 and 16");
                return;
            }
            cells[cellNumber - 1].turnOnOutputRelay();
            USBSerial.println("OK:output_enabled");
        } else if (command == "DISABLE_OUTPUT") {
            int cellNumber = args.toInt();
            if (cellNumber < 1 || cellNumber > 16) {
                USBSerial.println("Error:cell number must be between 1 and 16");
                return;
            }
            cells[cellNumber - 1].turnOffOutputRelay();
            USBSerial.println("OK:output_disabled");
        } else if (command == "ENABLE_LOAD_SWITCH") {
            int cellNumber = args.toInt();
            if (cellNumber < 1 || cellNumber > 16) {
                USBSerial.println("Error:cell number must be between 1 and 16");
                return;
            }
            cells[cellNumber - 1].turnOnLoadSwitch();
            USBSerial.println("OK:load_switch_enabled");
        } else if (command == "DISABLE_LOAD_SWITCH") {
            int cellNumber = args.toInt();
            if (cellNumber < 1 || cellNumber > 16) {
                USBSerial.println("Error:cell number must be between 1 and 16");
                return;
            }
            cells[cellNumber - 1].turnOffLoadSwitch();
            USBSerial.println("OK:load_switch_disabled");
        } else if (command == "ENABLE_LOAD_SWITCH_ALL") {
            for (int i = 0; i < 16; i++) {
                cells[i].turnOnLoadSwitch();
            }
            USBSerial.println("OK:all_load_switches_enabled");
        } else if (command == "DISABLE_LOAD_SWITCH_ALL") {
            for (int i = 0; i < 16; i++) {
                cells[i].turnOffLoadSwitch();
            }
            USBSerial.println("OK:all_load_switches_disabled");
        } else if (command == "PING") {
            USBSerial.println("OK:PONG");
        } else if (command == "CALIBRATE") {
            int cell_num = args.toInt();
            if (cell_num < 1 || cell_num > 16) {
                USBSerial.println("Error:cell number must be between 1 and 16");
                return;
            }
            cells[cell_num - 1].calibrate();

            USBSerial.println("OK:calibrated");
        } else if (command == "CALIBRATE_ALL") {
            for (int i = 0; i < 16; i++) {
                cells[i].calibrate();
            }
            USBSerial.println("OK:all_calibrated");
        } else {
            USBSerial.println("Error:unknown command");
        }
    }
}

void loop() {
    processUARTCommands();

    // Update LEDs every 100ms
    static unsigned long lastLEDUpdate = 0;
    if (millis() - lastLEDUpdate > 100) {
        updateStatusLEDs(cells, 16);
        lastLEDUpdate = millis();
    }

    // Update voltage targets at a reasonable rate
    static unsigned long lastVoltageUpdate = 0;
    if (millis() - lastVoltageUpdate > 10) {
        for (int i = 0; i < 16; i++) {
            cells[i].setVoltage(voltageTargets[i]);
        }
        lastVoltageUpdate = millis();
    }

    // Small delay to prevent busy-waiting
    delay(1);
}

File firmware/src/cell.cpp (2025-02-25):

#include "Cell.h"

// Constructor
Cell::Cell(uint8_t mux_channel, TwoWire& wire_interface) :
    mux_channel(mux_channel), wire(wire_interface) {
    // ...
}

// Implementation of public methods
void Cell::init()
{
    // Set the mux channel
    setMuxChannel();

    // Initialize DACs
    ldo_dac.begin(LDO_ADDRESS, &wire);
    buck_dac.begin(BUCK_ADDRESS, &wire);

    // Initialize ADC
    adc.begin(ADC_ADDRESS, &wire);

    // Configure GPIO expander
    wire.beginTransmission(0x20);
    wire.write(0x03); // Configuration register
    wire.write(0x00); // Set all pins as output
    wire.endTransmission();

    // Set the outputs to 0
    wire.beginTransmission(0x20);
    wire.write(0x01); // Configuration register
    wire.write(0x00); // Set all pins as output
    wire.endTransmission();
}

void Cell::disable()
{
    setMuxChannel();
    GPIO_STATE &= ~(1 << gpio_buck_enable);
    GPIO_STATE &= ~(1 << gpio_ldo_enable);
    setGPIOState();
}

void Cell::enable()
{
    setMuxChannel();
    GPIO_STATE |= (1 << gpio_buck_enable);
    GPIO_STATE |= (1 << gpio_ldo_enable);
    setGPIOState();
}

float Cell::getVoltage()
{
    setMuxChannel();
    int16_t adc_value = adc.readADC_SingleEnded(adc_output_voltage);
    float volts = adc.computeVolts(adc_value);
    return volts;
}

void Cell::setVoltage(float voltage)
{
    // Set the mux channel
    setMuxChannel();

    float buck_voltage = voltage * 1.05;
    float ldo_voltage = voltage;

    // Buck voltage limits
    if (buck_voltage < MIN_BUCK_VOLTAGE) buck_voltage = MIN_BUCK_VOLTAGE;
    if (buck_voltage > MAX_BUCK_VOLTAGE) buck_voltage = MAX_BUCK_VOLTAGE;
    if (ldo_voltage < MIN_LDO_VOLTAGE) ldo_voltage = MIN_LDO_VOLTAGE;
    if (ldo_voltage > MAX_LDO_VOLTAGE) ldo_voltage = MAX_LDO_VOLTAGE;

    // Set the output voltage
    setBuckVoltage(buck_voltage);
    setLDOVoltage(ldo_voltage);
}

void Cell::turnOnOutputRelay()
{
    setMuxChannel();
    GPIO_STATE |= (1 << gpio_output_relay_control);
    setGPIOState();
}

void Cell::turnOffOutputRelay()
{
    setMuxChannel();
    GPIO_STATE &= ~(1 << gpio_output_relay_control);
    setGPIOState();
}

void Cell::turnOnLoadSwitch()
{
    setMuxChannel();
    GPIO_STATE |= (1 << gpio_load_switch_control);
    setGPIOState();
}

void Cell::turnOffLoadSwitch()
{
    setMuxChannel();
    GPIO_STATE &= ~(1 << gpio_load_switch_control);
    setGPIOState();
}

float Cell::getCurrent()
{
    setMuxChannel();
    return readShuntCurrent();
}

// Implementation of private methods

float Cell::getLDOVoltage()
{
    setMuxChannel();
    int16_t adc_value = adc.readADC_SingleEnded(adc_ldo_voltage);
    float volts = adc.computeVolts(adc_value);
    return volts;
}

float Cell::getBuckVoltage()
{
    setMuxChannel();
    int16_t adc_value = adc.readADC_SingleEnded(adc_buck_voltage);
    float volts = adc.computeVolts(adc_value);
    return volts;
}

void Cell::setBuckVoltage(float voltage)
{
    setMuxChannel();
    uint16_t setpoint = calculateSetpoint(voltage, true);


    buck_dac.setVoltage(setpoint, false);
}

void Cell::setLDOVoltage(float voltage)
{
    setMuxChannel();
    uint16_t setpoint = calculateSetpoint(voltage, false);
    ldo_dac.setVoltage(setpoint, false);
}
// Implementation of helper methods

void Cell::setGPIOState()
{
    setMuxChannel();
    // Set output relay on P7
    wire.beginTransmission(TCA6408_ADDR);
    wire.write(0x01); // Output register
    wire.write(GPIO_STATE);
    wire.endTransmission();
}

float Cell::readShuntCurrent()
{
    setMuxChannel();
    int16_t adc_value = adc.readADC_SingleEnded(adc_output_current);
    float volts = adc.computeVolts(adc_value);

    return volts / SHUNT_RESISTOR_OHMS / SHUNT_GAIN;
}

void Cell::setMuxChannel()
{
    wire.beginTransmission(MUX_ADDRESS);
    wire.write(1 << mux_channel);
    wire.endTransmission();
}

void Cell::calibrate()
{
    // Calibrate the buck between 234 and 2625
    float delta = 2625 - 234;
    int step = round(delta / NUM_POINTS);
    for (int i = 0; i < NUM_POINTS; i++) {
        enable();
        turnOnOutputRelay();
        float setpoint = 234 + i * step;
        buck_dac.setVoltage(setpoint, false);
        delay(100);
        float voltage = getBuckVoltage();
        BUCK_SETPOINTS[i] = {voltage, setpoint};
    }

    // Set buck output to max
    buck_dac.setVoltage(234, false);
    delay(50);
    // Calibrate the ldo between 42 and 3760    
    delta = 3760 - 42;
    step = round(delta / NUM_POINTS);
    for (int i = 0; i < NUM_POINTS; i++) {
        enable();
        turnOnOutputRelay();
        float setpoint = 42 + i * step;
        ldo_dac.setVoltage(setpoint, false);
        delay(100);
        float voltage = getVoltage();
        LDO_SETPOINTS[i] = {voltage, setpoint};
    }
}

uint16_t Cell::calculateSetpoint(float voltage, bool useBuckCalibration)
{
    // Use the appropriate calibration array; each element is {measured voltage, DAC setpoint}
    const std::pair<float, float>* calibration_points = useBuckCalibration ? BUCK_SETPOINTS : LDO_SETPOINTS;
    const int numPoints = NUM_POINTS;
    // For descending data: clamp if voltage is above the maximum or below the minimum.
    if (voltage >= calibration_points[0].first) {
        return calibration_points[0].second;
    }
    if (voltage <= calibration_points[numPoints - 1].first) {
        return calibration_points[numPoints - 1].second;
    }
    // Find the first index where the measured voltage becomes less than or equal to the target.
    int index = 1;
    while (index < numPoints && calibration_points[index].first > voltage) {
        index++;
    }
    int above_index = index - 1;
    int below_index = index;
    if (above_index == below_index) {
        return calibration_points[above_index].second;
    }
    // Linear interpolation:
    // DAC setpoint = s1 + (voltage - v1) * (s2 - s1) / (v2 - v1)
    float v1 = calibration_points[above_index].first;
    float v2 = calibration_points[below_index].first;
    float s1 = calibration_points[above_index].second;
    float s2 = calibration_points[below_index].second;
    float m = (s2 - s1) / (v2 - v1);
    float b = s1 - m * v1;
    return static_cast<uint16_t>(m * voltage + b);
}

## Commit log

2024-07-25 Configure project
    [cell-sim.kicad_pcb, cell-sim.kicad_sch]
2024-08-09 fix imports
    [esp32-s3.kicad_pcb, esp32-s3.kicad_sch, level-shifter.kicad_pcb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]
2024-08-09 updated imports
    [cell.kicad_pcb, cell.kicad_sch, ldk220m-r.kicad_pcb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]
2024-11-06 add limits and calibration points
2024-11-06 add leds
2024-11-06 cleanup net names
    [cell.kicad_pcb]
2024-11-07 add library parts
    [cell-sim.kicad_pcb, cell.kicad_pcb, template_40x40.dxf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]
2024-11-12 use linked modules, remove local cache
    [level-shifter.kicad_pcb, level-shifter.kicad_sch, lv2842xlvddcr.kicad_pcb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]
2024-11-12 update i2c pins
2024-11-13 add VSH connector
2024-11-13 added ethernet
    [ethernet.kicad_pcb, ethernet.kicad_sch]
2024-11-13 add components to thermistor simulator
2024-11-13 Add thermistor connections to Molex VSH + finish layout
2024-11-30 connect ethernet gnd to main gnd and update layout
2024-12-03 Update i2c pinouts
2024-12-03 fix pinouts, cleanup main example
    [cell.cpp, cell.h, main.cpp]
2024-12-04 Config mux to git rid of chatter, add print for Serial terminal
    Abstract out wire interface, no all 16 cells are functional
    Patch to increase NUM_LEDS now that all cells are enabled
    Update LDO and Buck DACs to use appropriate wire as well
2025-02-04 add load switch + output relay support + dmm enable/disable
2025-02-25 Added self calibration routine on boot
